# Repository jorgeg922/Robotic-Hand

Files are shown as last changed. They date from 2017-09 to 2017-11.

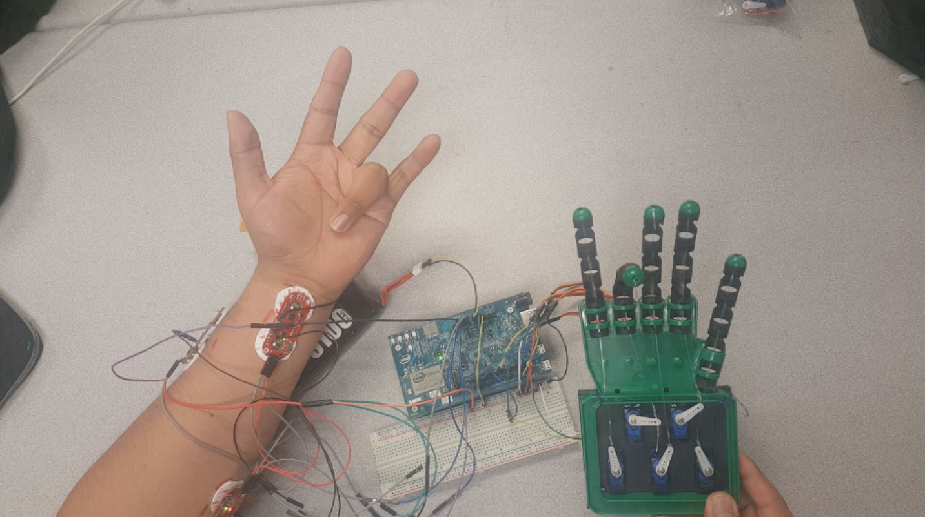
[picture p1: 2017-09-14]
Images/snip.PNG

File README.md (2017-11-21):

# Project Need-A-Hand
# RoboticHand

Team Members:
Espinoza, Jesus; Gonzales, Jorge; Guzman, Omar; Ladesma, MarcoAntonio

The purpose of this project was to develop a robotic hand that may be used to aid amputees regain full use of their hands.
This project, through the use multiple advanced sensors reads the eletrical differential potentials from an individual's arm muscles and
converts the signals to their equivalent PWM signal to move the fingers from the robotic hand.

Due to the complex nature of reading electrical signals from people's arms, this project includes a calibration procedure developed by the team mentioned above, which allows the user to more easily control the hand through his/her muscles. Furthermore, due to the different physical attributes of each individual the results may still vary as muscle location may differ per individual. However, in the documentation we have included a general diagram that may help you find the correct location of your muscles.

For set-up instructions and demonstration images/videos, please refer to the files included within this repository.

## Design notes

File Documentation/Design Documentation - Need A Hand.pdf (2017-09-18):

# Design Documentation

# Spring 2016

# Team 6: Need-A-Hand

## Group Members: MarcoAntonio Ledesma

## Jesus Espinoza

## Omar Guzman

## Jorge Gonzales

Table of Contents

## ABSTRACT

Need-A-Hand: Muscle Sensor Controlled Prosthetic Hand for those with Hand Disabilities

Need-A-Hand is a project to create a prosthetic hand that is controlled using muscle sensors in

the forearm. The purpose of this project is to build a prosthetic robotic hand to aid those

people who have a hand disability. The prosthetic hand will help those people regain some

hand ability to aid them in daily tasks like getting dressed, cooking a simple meal, grasping a

glass to drink water. In the end our goal is to make life easier to those with an unfortunate hand

disability.

If you look into hand anatomy, we can see that human fingers move with the muscles in the

palm and forearm. Instead of using those muscles in the forearm to move real fingers we will

use them to move our prosthetic hand fingers. This is where the basic functionality of our

prosthetic hand comes from. We will be using muscle sensors to read muscle activity in our

forearm. The muscle sensors read muscle contractions to get a signal. We then use those

signals to activate servos to individually move the fingers of the prosthetic hand.

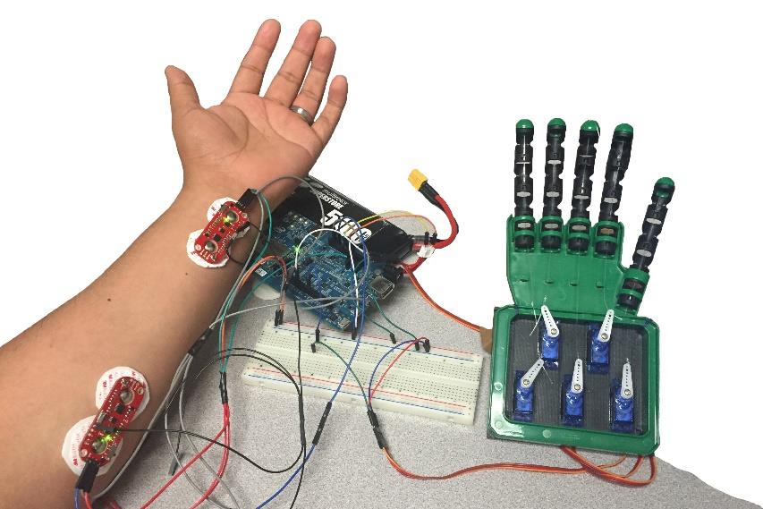
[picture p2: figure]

## Introduction

The motivation behind our project was that there are a lot of people with hand disabilities who

have lost their ability to complete daily tasks especially those of physical nature after having

one of their hands amputated such as war veterans or people suffering from malignant

diseases. Currently, the options on the market for people who have had one of their hands

amputated are to buy a plastic prosthetic hand or invest on a robotic prosthetic hand which can

cost up to $100,000 per unit.

However, these options are either insufficient to help an individual complete basic daily tasks or

too expensive for a common individual to afford. Therefore, with the inspiration to improve

people's lives, our project began as an idea to develop a robotic prosthetic hand that would

allow people to perform and complete necessary and essential tasks such as clothing

themselves more efficiently, driving, or even cooking by controlling each of the fingers in the

robotic hand. Our goal was to develop the robotic prosthetic hand that would result in an

inexpensive, but efficient product that would be easy for the person the use.

In understanding this project there were 3 major tasks to accomplish. First, we needed to figure

out how we would be reading the signals from the arm muscles that belonged to each

individual finger. Second, given the signal, we needed to find a way to interpret the signal and

pass it to our robotic hand for movement. Third, we needed to design our robotic hand in a way

that the fingers could move according to the data being received from the actual muscles

allowing the user to perform the desired task.

## Product Proposal both Fall and Spring Semesters

CPE 190: Project Proposal

Project Name: Need-A-Hand

Team 6 Members:

Espinoza, Jesus; Gonzales, Jorge; Guzman, Omar; Ladesma, MarcoAntonio

Purpose and Justification

The purpose of this project is to design and build a prosthetic robotic arm to aid those who

have lost part of their limbs in accidents or military combat. The prosthetic arm will help

improve the quality of life of those who have lost a hand by giving them the ability to once

again be able to perform basic daily tasks that may need the ability to use individual fingers in

order to accomplish them.

Statement of the Problem or Need

Many people have lost the ability to fully enjoy life due to the loss of an arm, either through

unfortunate life events or military combat. This has caused many people difficulties integrating

themselves into society because some of the simplest daily tasks such as changing clothes

required the use of both hands. This unfortunate disability has created a need for engineers to

develop replacement arms. The user will be able to control this robotic prosthetic arm through

the use of muscle sensors by reading the electrical signals outputted by the muscles that may

still remain in the arm. The robotic arm will simulate the functions of the original limb and will

allow its users to better perform their daily tasks by being able to move each finger individually

with the correct amount of force necessary to perform the task.

As of now, there are other robotic arms people have access to, but these arms are very costly

to the consumer and very few can afford them. However, with the introduction of development

microcontroller kits, people have access to the same technology many big firms do for a lot

cheaper. This project will allow more people to have access to a robotic arm that will improve

their quality of life by making use of devices that are available to the general public.

Project Deliverable and Beneficiaries

- Develop functionality code in C++ - includes code to pick up electrical readings from muscle sensors and map them to the servos.
- Create GUI for electrical signal readings in Java - includes code to read the electrical signals and outputs them to a graph in order to calibrate muscle sensors.
- Test prototype on selected subject – test the first prototype on a person who has full use of both arms.
- Second stage of the project will required a 3D printed hand to better fit the needs of the user.
- Test prototype on final subject – test final design on a person who has lost a partial arm (fall semester).
- At the end of the project, we hope to have a fully functioning prosthetic robotic arm. With the use of sensors, the user will be able to control the arm and will be able to perform simple tasks such as cracking an egg open with both arms.

Knowledge Areas Needed for Project

- Software engineering
- Hardware design
- Circuit Analysis

Time Factors

We would like to start with the research of this project as soon as possible. Documentation of

the hardware as well as the software design will need to implemented as soon as possible in

order to complete the project. The end of the semester is coming near and we would like to

have a completed budget in the following week.

Project Assumptions and Constraints

Assumptions:

- The prosthetic arm will be able to be tested on a person with both arms
- All members are able to learn the required material in the allotted time
- All hardware will be available for purchase
Constraints:
- The prototype must be completed before the end of the Spring 2016 semester

Project Risks

- There is a risk that the hardware may not be available for purchase or that the project may need more skills in the field of mechanical engineering

## WBS and Schedule including milestones

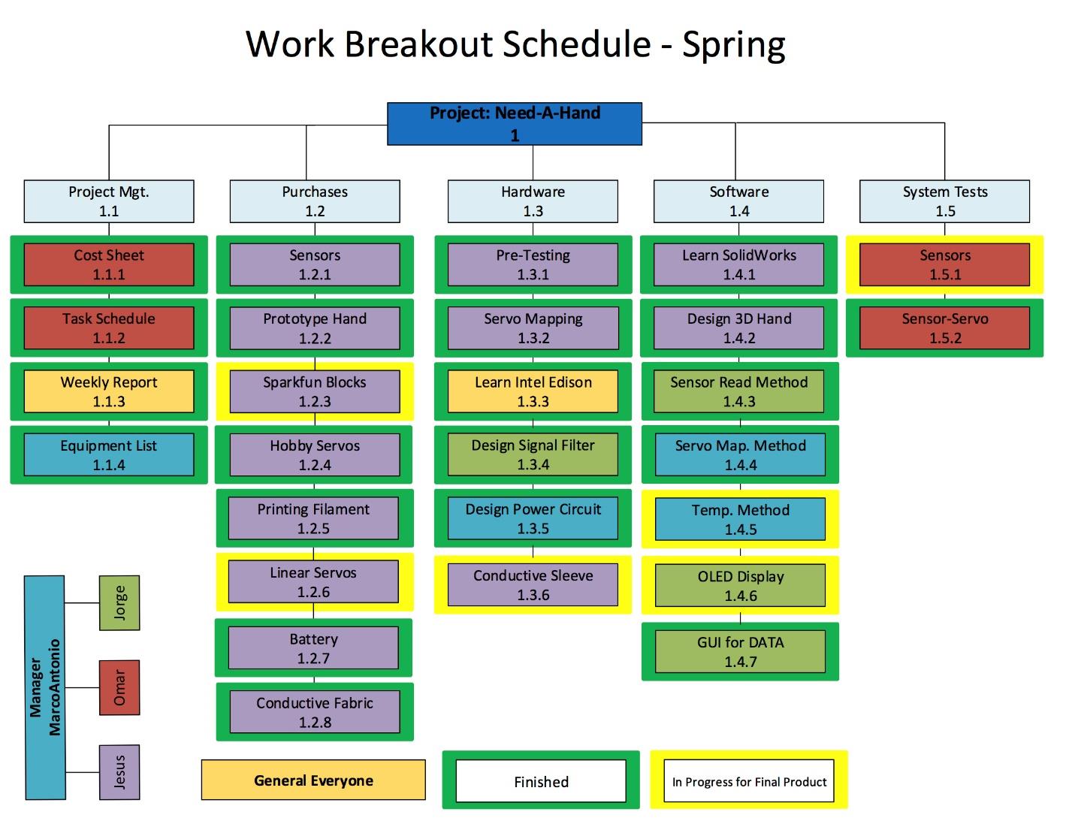
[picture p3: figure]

Above we have our WBS for the spring. It is color coded to highlight which team member is

assigned which task. It also highlights which tasks have been finished and which ones are in

progress or to be implemented in the final product design.

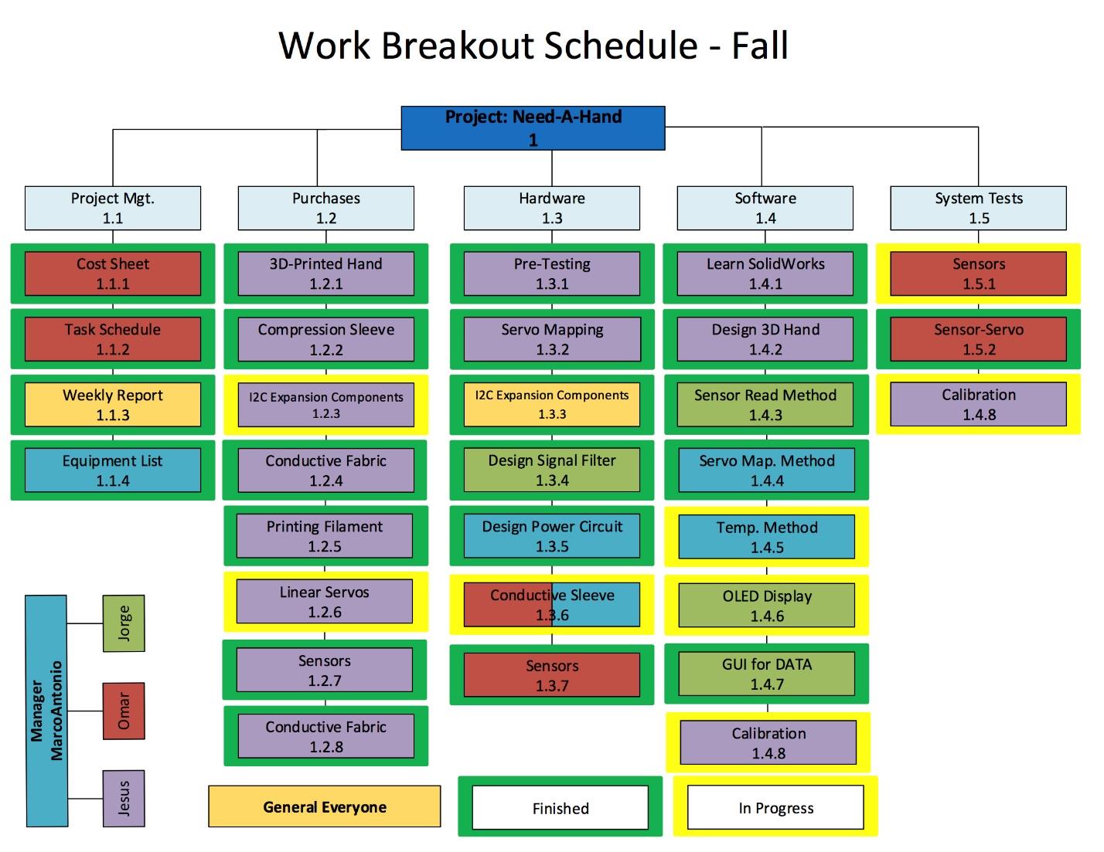
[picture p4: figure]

Above we have our WBS for the fall semester. Again just like before it is color coded to

highlight which team member is assigned which task. It also highlights which tasks have been

finished and which ones are in progress. As you can see it includes many components of the

previous first phase design as we are still using some of the components and continue

optimizing those parts.

ID | Task Name
1 | 1 Need‐A‐Hand
2 | 1.1 Project Mgt.
3 | 1.1.1 Cost Excel Sheet
4 | 1.1.2 Tasks Schedule
5 | 1.1.3 Weekly Progress Report
6 | 1.1.4 Equipment List
7 | 1.2 Purchases
8 | 1.2.1 Muscle Sensor
9 | 1.2.2 Prototype Hand
10 | 1.2.3 Sparkfun Blocks
11 | 1.2.4 Hobby Servos
12 | 1.2.5 3D Printing Filament
13 | 1.2.6 Linear Servos
14 | 1.2.7 Battery
15 | 1.3 Hardware
16 | 1.3.1 Pre‐Test Muscle Sensor
17 | 1.3.2 Map Servo with Muscle Sensor Readings
18 | 1.3.3 Learn Intel Edison Hardware
19 | 1.3.4 Design Signal Filter for Muscle Sensor Reading
20 | 1.3.5 Design Power Circuit
21 | 1.4 Software
22 | 1.4.1 Learn SolidWorks
12 | 17 | 22 | 27 | 3 | 8 | 13 | 18 | 23 | 28 | 2 | 7 | 12 | 17 | 22 | 27 | 2 | 7 | 12 | 17 | 22 | 27
016 | March 2016 | April 2016 | May 2016

Task
Split
Milestone
Summary
Project Summary
Inactive Task
Inactive Milestone

Inactive Summary
Manual Task
Duration-only
Manual Summary Rollup
Manual Summary
Start-only
Finish-only

External Tasks
External Milestone
Deadline
Progress
Manual Progress

Project: Project1
Date: Tue 3/15/16

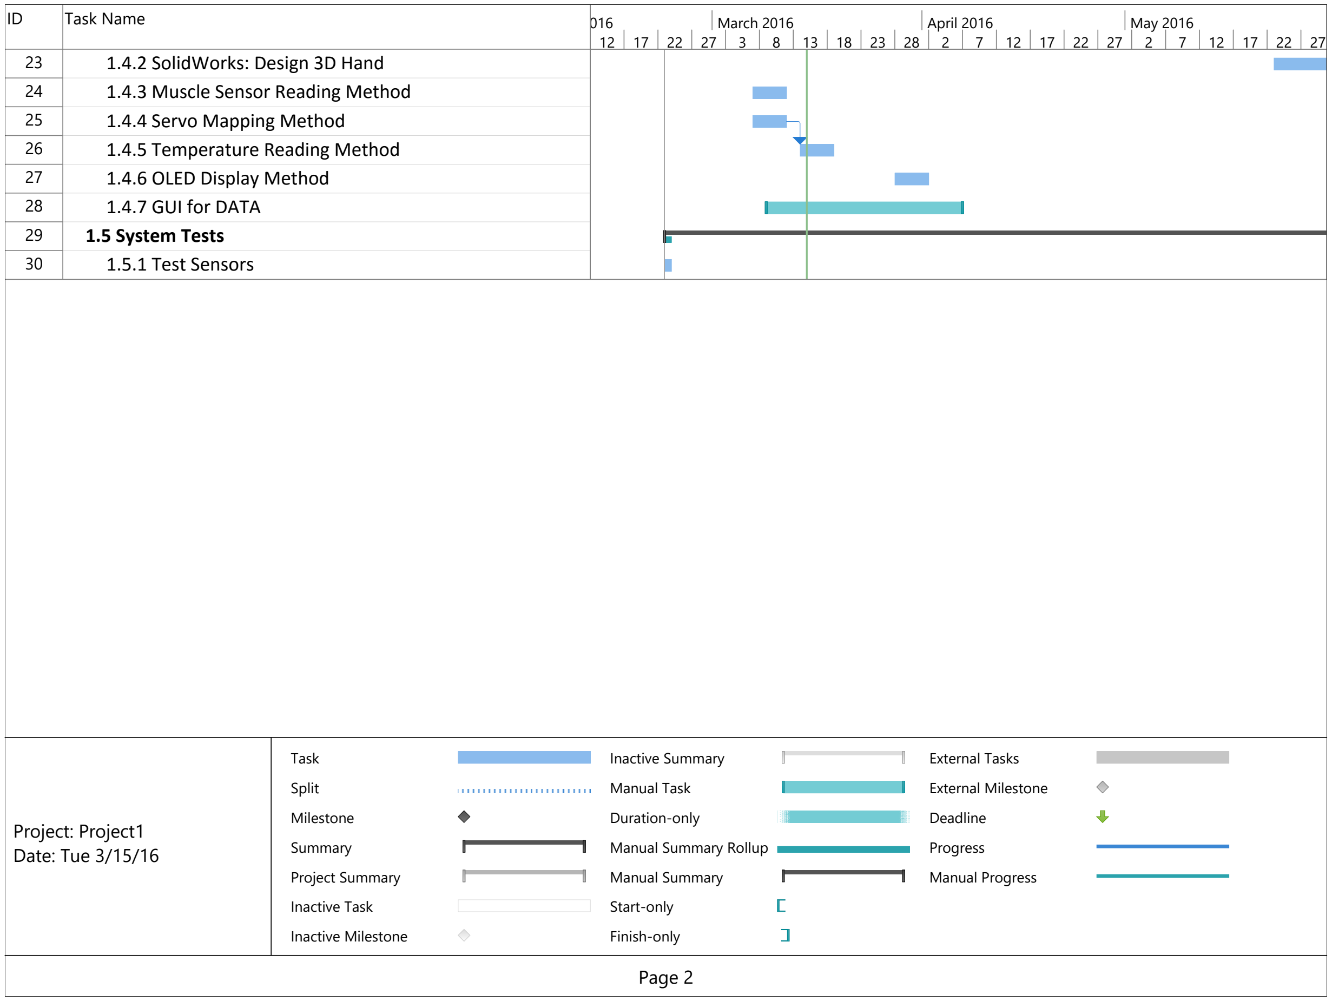
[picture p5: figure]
Task Name; 1.4.2 SolidWorks: Design 3D Hand; 1.4.3 Muscle Sensor Reading Method; 1.4.4 Servo Mapping Method; 1.4.5 Temperature Reading Method; 1.4.6 OLED Display Method; 1.4.7 GUI for DATA; 1.5 System Tests; 1.5.1 Test Sensors; March 2016; April 2016; May 2016; Task; Split; Milestone; Summary; Project Summary; Inactive Task; Inactive Milestone; Inactive Summary; Manual Task; Duration-only; Manual Summary Rollup; Manual Summary; Start-only; Finish-only; External Tasks; External Milestone; Deadline; Progress; Manual Progress; Project: Project1 Date: Tue 3/15/16

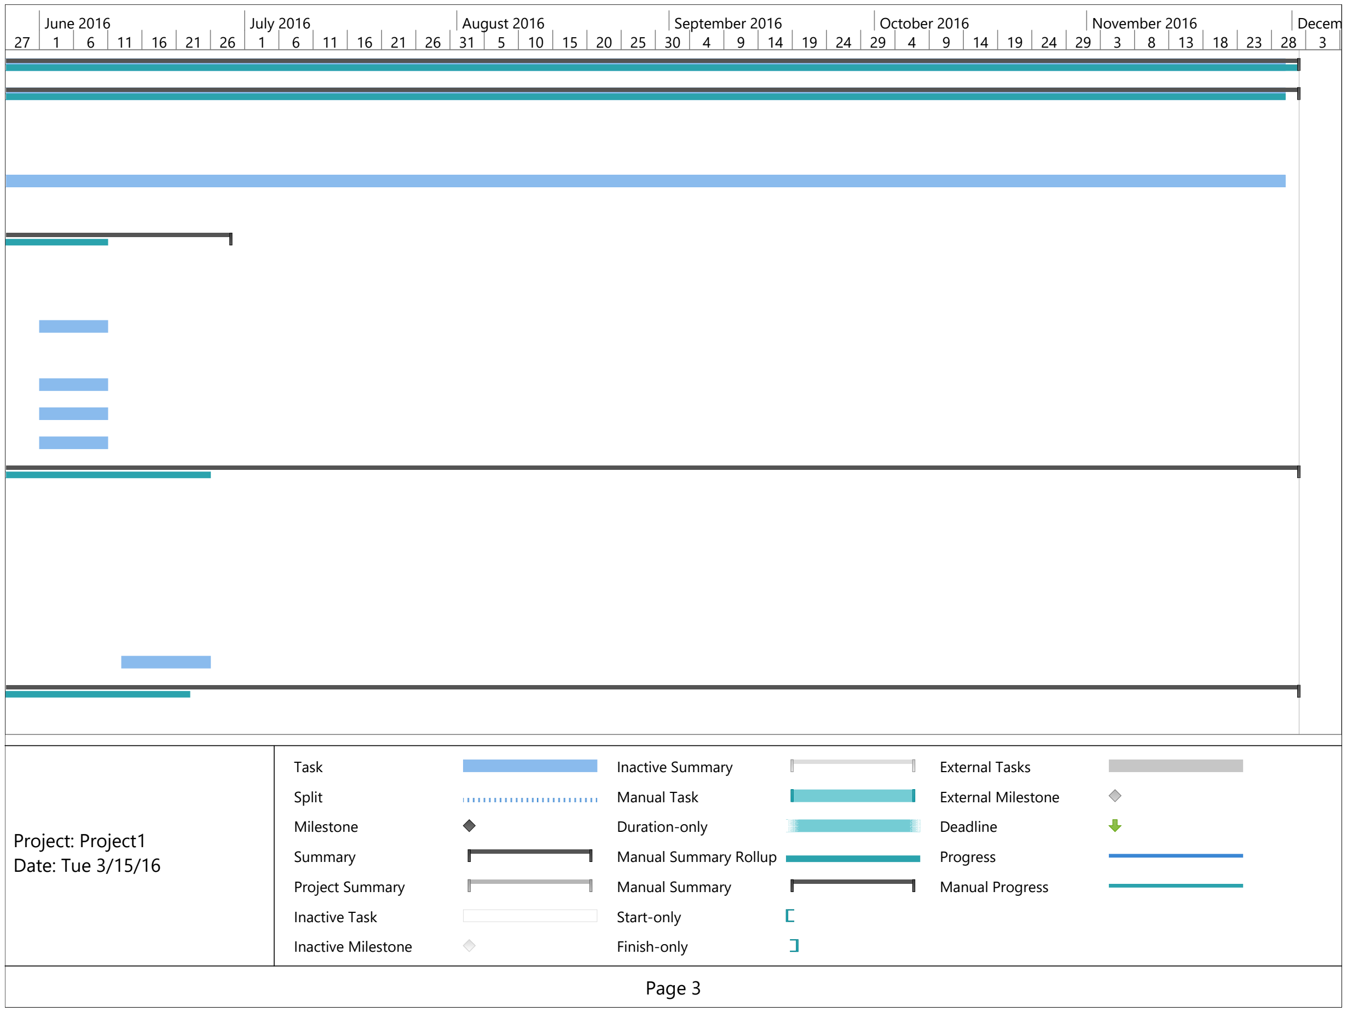
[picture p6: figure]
June 2016; July 2016; August 2016; September 2016; October 2016; November 2016; Decem; Task; Split; Milestone; Summary; Project Summary; Inactive Task; Inactive Milestone; Inactive Summary; Manual Task; Duration-only; Manual Summary Rollup; Manual Summary; Start-only; Finish-only; External Tasks; External Milestone; Deadline; Progress; Manual Progress; Project: Project1 Date: Tue 3/15/16

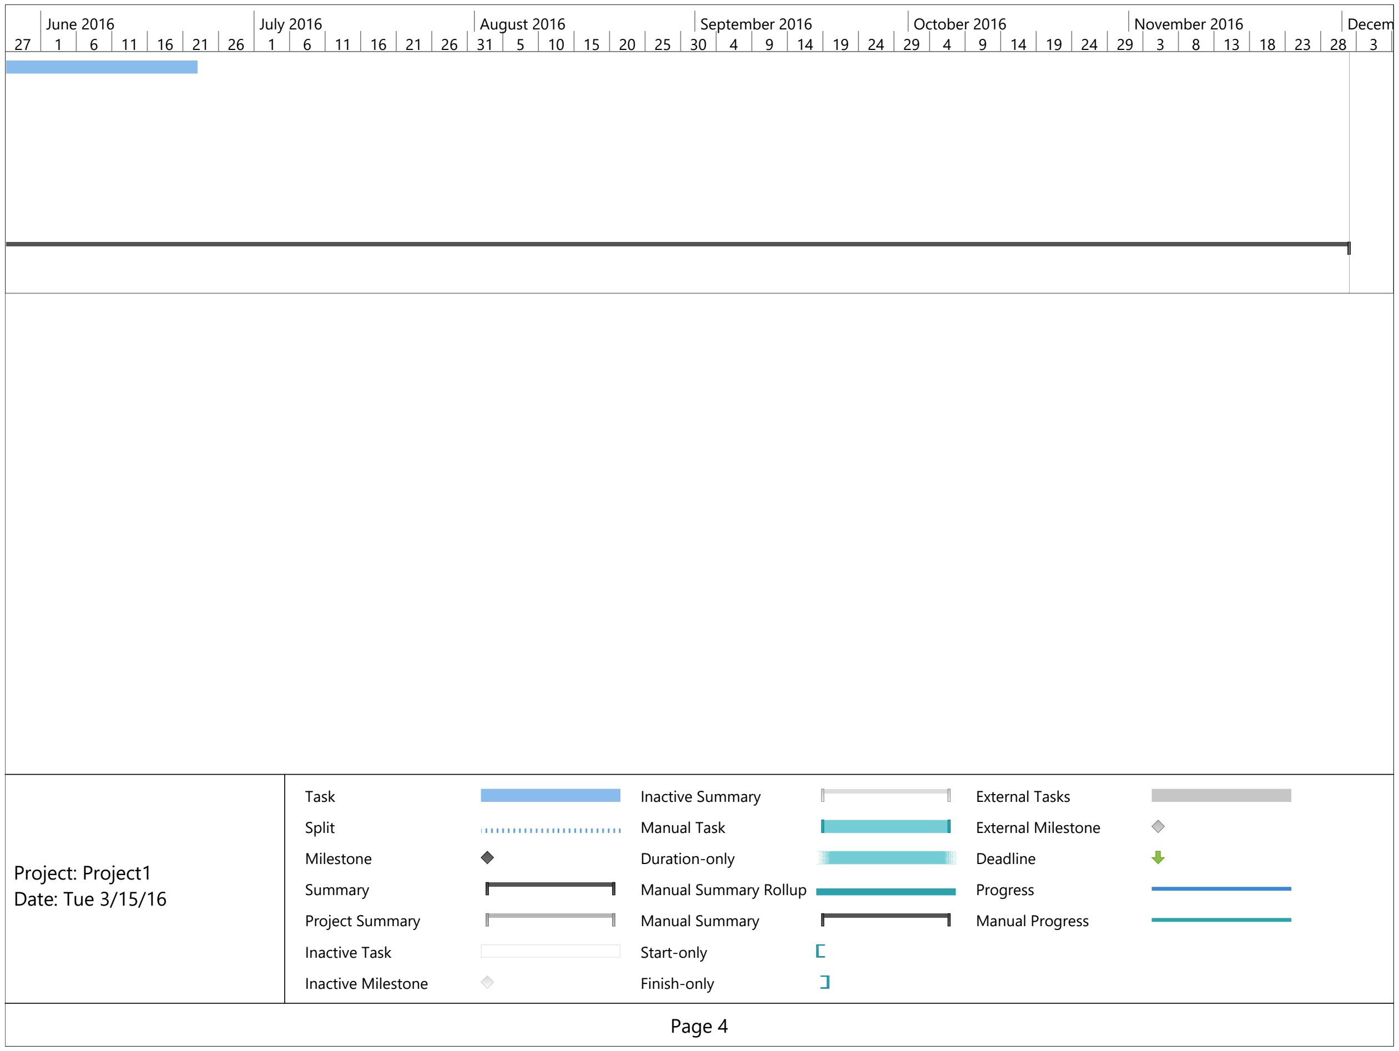
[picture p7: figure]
June 2016; July 2016; August 2016; September 2016; October 2016; November 2016; Decem; Task; Split; Milestone; Summary; Project Summary; Inactive Task; Inactive Milestone; Inactive Summary; Manual Task; Duration-only; Manual Summary Rollup; Manual Summary; Start-only; Finish-only; External Tasks; External Milestone; Deadline; Progress; Manual Progress; Project: Project1 Date: Tue 3/15/16

## Funding Proposals

The goal of our project is to engineer an affordable prosthetic hand to aid those for

hand disabilities. For the reason of making it affordable this project should be affordable for

ourselves as well. We are funding the project ourselves not only to emphasize the affordability

but also to have full ownership of any biomedical engineering advances we may succeed in.

Below is the total cost of the project broken down by components.

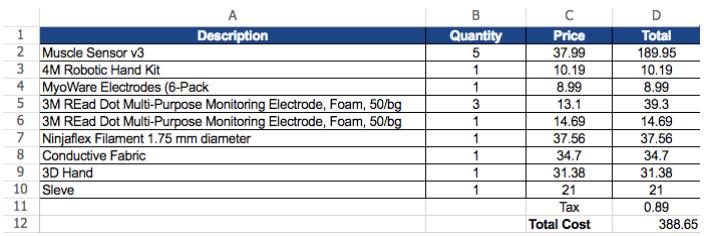
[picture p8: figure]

We have yet to purchase our linear servos and I2C components. We estimate that will bring

our cost up to about $600. Even then that cost between 4 people is only $150 each. Which is

affordable for a yearlong project. This is why we decided to fund the project ourselves. In the

end we also get full ownership so that is good.

## Team Member Tasks

Once we determined the work breakdown schedule, we needed to make each member of the

group responsible for certain tasks. We split the tasks amongst ourselves by assigning a

responsible person as well as a back-up person to a task. The "back-up" was set up in case

something happened to the person responsible for the task in order to avoid delays in the

development of the project.

We broke down the tasks in the following way:

Task | Assigned to | Backup
Cost Sheet | Omar | Jesus
Keeping track of the cost of every component being purchased for the development of the project. Also, keeping track of how much each member owes
Weekly Report | MarcoAntonio | N/A
Updating the weekly report with the team minutes from each week's minutes. Also, responsible for submitting the report after each member has updated the report with their respective task progress.
Equipment List | MarcoAntonio | Jesus
Responsible for tracking the amount of parts being purchased for the project. Also, responsible for keeping track of the equipment being used and for putting in a purchase request if we run of out parts such as gel pads and/or wires
Purchases of components | Jesus | MarcoAntonio
Responsible for the purchase of the components necessary to complete the project after request has been agreed upon by the member of the group. Also, responsible for updating the cost sheet after each purchase
Learning Intel Edison tools | General Team | N/A
Each member of the team is responsible for learning the appropriate tools within Intel Edison for the purposes of this project. This includes, but is not limited to learning the IDE by Eclipse which is used to compile our C++ based code.
Design Signal Filter | Jorge | Jesus

Responsible for the development of a system to filter the signals being read by the muscle sensors whether by using additional hardware or developing some code

Design Power Circuit | MarcoAntonio | Omar
Responsible for the design and implementation of the power circuit
Conductive Sleeve | Jesus | MarcoAntonio
Responsible for the design and implementation of the conductive sleeve to better pick up the electric signals from the muscles
Learn SolidWorks | Jesus | General Team
Responsible for learning SolidWorks which will be used to design the custom 3D hand for the fall semester
Design 3D Hand | Jesus | MarcoAntonio
Responsible for the design of the 3D hand to be used on the amputee. This 3D hand is supposed to fit in a real human being.
Method to read sensor signals | Jorge | Jesus
Develop C++ code to read the signals from the MyoWare muscle sensors and pass them to the Intel Edison
Method to map the servos | MarcoAntonio | Jesus
Develop C++ code to convert the stored data from the muscle sensors into a signal that can be mapped using the servos attached to the robotic hand in order to produce movement
Temperature Method | MarcoAntonio | Jorge
Develop C++ code to be able to read the surrounding temperature and report it back to the user
OLED Display | Jorge | Omar
Responsible for the implementation of the OLED display to report the surrounding temperature
Graphic User Interface | Jorge | Jesus
Responsible for the graphic user interface which will plot each signal being read from the muscle sensors
Sensor Testing | Omar | MarcoAntonio
Responsible for the testing and debugging of the sensors and any other hardware/software that may be showing errors
Sensor-Servo communications | Omar | Jorge
Responsible for the communications between the sensors and servos. This includes, but is not limited to wiring and circuit analysis

## User Manual

The artificial robotic hand uses 5 muscle sensors (Figure 1.1) to obtain an analog signal from the

muscle contractions. Which are the filtered and translated to servo positions which controls

each finger.

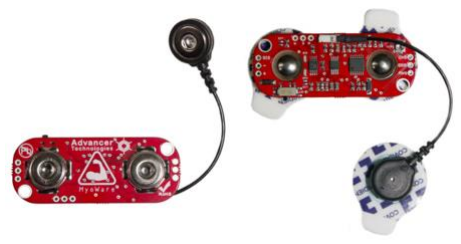
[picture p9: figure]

Figure 1.1 (http://www.advancertechnologies.com/p/myoware.html)

Muscle Position and Sensor Placing

The five sensors will be placed around the forearm and a common ground on the elbow. Please

see the muscle sensor placement (Figure 1.2) to find the best muscle position to obtain a clean

signal.

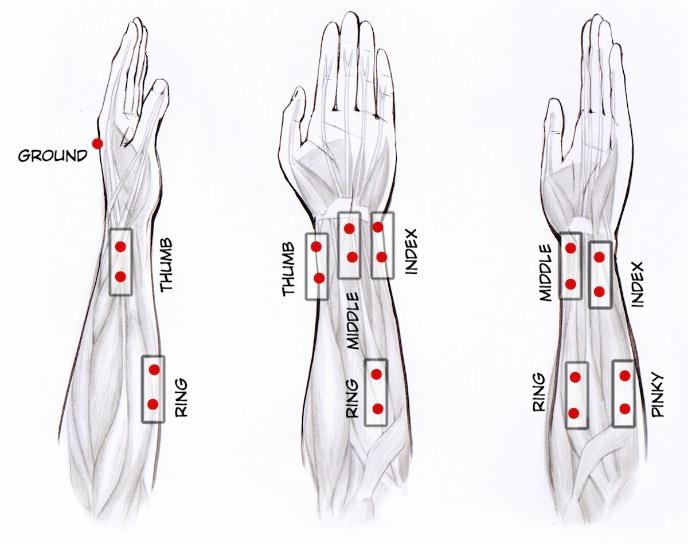
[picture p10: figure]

Figure 1.2 (https://backyardbrains.com/experiments/robothand)

The sensors will require two electrode pads each and an electrode pad for the common ground.

Before placing each sensor on the forearm, make sure to clean your skin with rubbing alcohol,

or conductive gel to obtain better readings.

Each sensor is labeled as P, R, M, I, and T (Pinky, Ring, Middle, Index, and Thumb) place each

sensor according to the position from Figure 1.2. Place the common ground electrode near a

bone, we strongly suggest using the elbow since there are not many muscles around the elbow.

Each sensor will have four wires connected, Signal, Power, Ground, and Reference electrode.

Make the following connections to each sensor.

Muscle Sensor | Intel Edison pin
+ | 5V
- GND
Sig | A0-A4
R (Reference Electrode | N/A

The reference electrode will connect each sensor to each other using the 1:4 female connector

cable. The pinky sensor will be closed to the elbow, use this sensor to obtain the reference

electrode from the elbow. Then connect the 1:4 female connector cable from the “R” pin on

the sensor to the “R” pin on the other four muscle sensors.

Connect the battery to Intel Edison, you should see the sensors LED’s light up. The Servos

should start moving now.

Muscle Sensor Calibration

If the servos are not moving full range and/or not responding to the muscle sensors. You will

need to start the calibration process by pressing the calibration button. Once the calibration

process starts, you will need to do two actions to calibrate the sensors for each finger

individually.

1. To define the baseline, relax your muscle for 10 seconds.
2. To define the Max value, you will need to pulse the muscle by contracting the muscle

and relaxing multiply times for 10 seconds.

3. Repeat these steps for each sensor.

Once the calibration process is finished, the servos should be responding. If they are not, you

can attempt to calibrate again.

## Design Documentation (Spring & Fall)

The purpose of this design is to aid people without a hand, whether they lost their hand

in combat, birth defects, or an unfortunate tragedy. Our design will use the Intel Edison to take

analog signals generated from muscle contraction and translate/convert the signals to hand

movement that will be used to control a 3D printed artificial hand. The user will mount all the

sensors and the Edison module on their forearm.

In the spring semester we were able to design and built a prototype design to prove the

idea and logic behind our design. Currently we have four sensors reading muscle contraction

signals, the logic for five sensors is implemented and tested but due to a hardware limitation on

the Intel Edison Arduino board, which is only capable of driving four PWM signals at a time. This

will be addressed in the fall semester.

During the spring semester we came across a couple of obstacles that we successfully

overcame. Our first obstacle was finding a power supply to drive five servos. Since the servos

can draw up to 2A each, we are using a Li-Po battery that is able to continuously output 150A

which is more than enough. This gave us the idea to use a smaller battery for the final design,

since the Edison module is low power the battery will last longer. We can design an algorithm

that will help decide to turn off the power being applied to the servos in order to save battery.

Another challenge that we overcame was getting the muscle sensor signals. Since the muscle

sensors contract the signal varies between 1 – 2 Volts. The signals were originally mapped to

the servos without being modified. What we decided to do, was design the calibration

algorithm to calibrate the sensors, essentially what it does is find the baseline and max value for the sensors. Then we take around 1 hundred samples and find the average to rule out the

outliers.

For the Fall semester we plan to migrate our design to the Intel Edison breakout board,

which will allow us to condense our design into a smaller form factor that will be mounted on

the forearm of the user. We also intend to implement an I2C OLED display to provide the user

visual feedback from calibration process and/or battery voltage.

## Software Block Diagram & Documentation

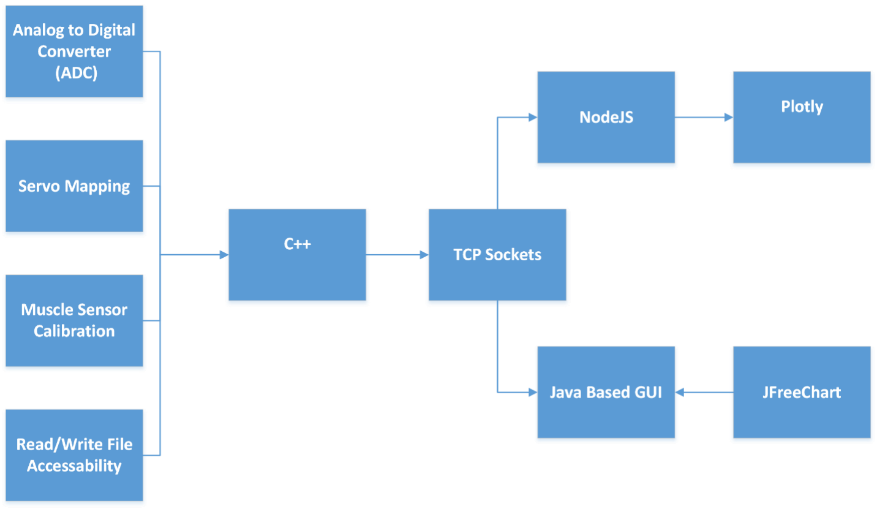
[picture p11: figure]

The software designed in our project is based on C++ and NodeJS, both which are

simultaneously running on the Intel Edison Development Platform. The Intel Edison board is

running an embedded version of Linux based on the Yocto Project which has Wi-Fi capabilities.

The C++ contains the following logic.

- Read analog signals and converting to digital.
- Mapping the sensor readings to an angle to be written to the servo
- Client TCP socket
- Muscle sensor calibration logic
- I/O Interfacing and Initialization
- Read and Write to file where calibration values are stored.

The NodeJS contains the following logic.
- Server TCP socket
- Plotly API to send data to Graph

The Java based GUI contains the following logic.
- Server TCP socket
- JFreeChart to graph data

## Hardware Block Diagram & Documentation

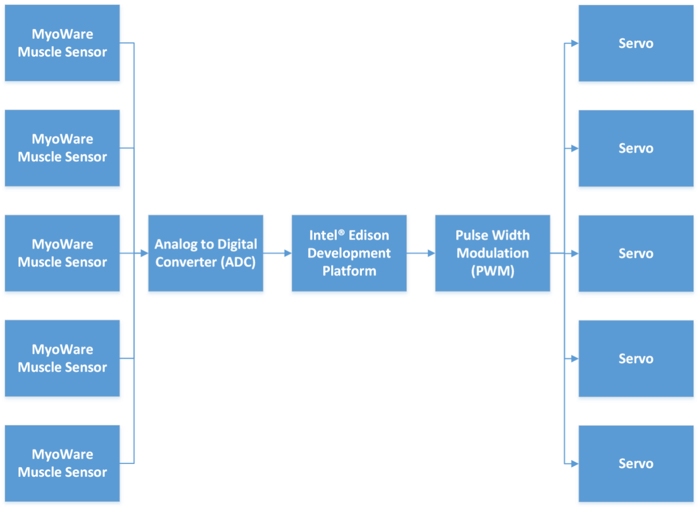
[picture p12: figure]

The Intel Edison Development platform was our best option for our project for various reasons.

The fast prototyping can then be easily transferred into a smaller board to design wearable

technology. In this case, the Edison module will be mounted onto the design that will be on the

users forearm along with all the sensors. The muscle sensor reads EMG signals that can be read

with an ADC chip.

The current Arduino Expansion board has an analog to digital (ADC) chip which allows us to

sample a analog signal, a pulse width modulation driver which allows us to send a pulse signal to the Servos. A Bluetooth and Wi-Fi module are built in to the module that allows us to

connect to a network to send data to the GUI or Plotly to graph the muscle sensor readings.

The Intel Edison module will allow us to transfer our current project and enhance the hardware

by using external PWM and I2C chips to expand the capabilities but at the same time

condencing our project to allow the comfort of being on the forearm of a person.

## Software

In order to develop the software necessary to operate the robotic prosthetic hand, we decided

to write the code in C++ language using the Eclipse IDE.

The following are some excerpts of the code we wrote in order for the hand to operate.

int mmap(int, int, int, int, int);

void my_socket(int, int, int, int, int);

void readCalibration();

void Calibration();

In the portion of the code shown above, we simply declared the mmap function used to map

the signals to the servos. We declared the socket as well as the calibration methods that we will

be demonstrating later in this report.

int s0 = socket(AF_INET, SOCK_STREAM, 0);

char const *peerHost = "127.0.0.1";

short peerPort = 8589;

struct sockaddr_in peeraddr;

In this portion of the code we defined the socket and assigned the IP address the socket will be

communicating with. We also assigned the port number.

upm::ES08A *servo0 = new upm::ES08A(3);

upm::ES08A *servo1 = new upm::ES08A(5);

upm::ES08A *servo2 = new upm::ES08A(6);

upm::ES08A *servo3 = new upm::ES08A(9);

servo0->setAngle (180);

servo1->setAngle (180);

servo2->setAngle (180);

servo3->setAngle (180);

Next, we set up the pins from which the servos would be acquiring the signal first acquired

from the muscle sensors to produce movement in the fingers. We also set the servos to an

initial angle of 180 degrees that signified the hand was relaxed and fingers spread out.

int count = 0;

int samples = 30;

for (;;) {

usleep(3000);

pinky_val += a0->read();

index_val += a3->read();

my_socket(pinky_val,ring_val,middle_val,index_val,0);

if(count == samples){

pinky_val = (((pinky_val+5)/10) * 10)/samples;

…

In the above code, we set up some parameters before the signal was passed on to the servo to

be mapped. We decided to take 30 data samples. After these samples were taken and added

together, the number was rounded to its closes multiple of 10 and the average was taken. This

allowed us to reduce the shaking of the hand and resulted in smoother and more accurate

movement.

if((pinky_low) < pinky_val && pinky_val < (pinky_high + 1)){

pinky_servo = mmap(pinky_val, pinky_low, pinky_high, 180, 0);

servo0->setAngle (pinky_servo);

}

After the calculations previously mentioned were done, we compared our new value to the

high and low threshold and if it was in between these values, it was then passed unto the servo

to rotate to certain degree in order to move the robotic fingers.

void readCalibration(){

ifstream file("/home/root/calibration.txt");

if(file.is_open()){

for(int i = 0; i < 10; i++){

file >> cali_val[i];

}

}

file.close();

}

In the above method, we set up the way in which we would read the high and low threshold

values stored in a text file.

void Calibration(){

int tmparray[10] = {0,0,0,0,0,0,0,0,0,0};

int count;

int tmpvar = 0;

int samples = 1500;

printf("Order of calibration: Pinky, Ring, Middle, Index, Thumb\n");

printf("Calibrate each finger twice: Baseline, then Max\n");

printf("Calibration process will start in 3 seconds\n");

printf("\n");

sleep(3);

printf("Calibrating Baseline for Pinky\n");

for(count = 0; count < samples; count++){

tmpvar += a0->read();

usleep(5000);

}

tmparray[0] = tmpvar/samples;

tmpvar = 0;

printf("Calibrating Max for Pinky\n");

for(count = 0; count < samples; count++){

tmpvar += a0->read();

usleep(5000);

}

ofstream file("/home/root/calibration.txt");

if(file.is_open()){

for(int i = 0; i < 10; i++){

file << tmparray[i];

file << " ";

}

}

file.close();

printf("Calibration Finished...\n");

}

void my_socket(int sval1, int sval2, int sval3, int sval4, int sval5){

const void *data;

std::string sensor1 = SSTR( sval1 );

std::string sensor5 = SSTR( sval5 );

std::string my_string = sensor1 + "," + sensor2 + "," + sensor3 + "," + sensor4 + "," + sensor5;

data = my_string.c_str();

write(s0, data, 20);

}

In the Calibration method, which is one of the most important parts of this code, we acquire

the values for the high and low threshold for each individual finger. The above code only shows

the code for one finger as we found it redundant to post the code for each individual finger

since the code is the same. Nevertheless, we acquired the threshold values by reading 1500

samples and averaging them out. For the low threshold value we maintained our hand relaxed,

and for the high threshold value, we contracted our finger fully several times until the

calibration process was completed.

## Hardware

MyoWare Muscle Sensors

The Myoware muscle sensor measures muscle activation via electric potential, referred to as

electromyography (EMG). This muscle sensor is place around our forearm to read finger muscle

activity in our arm due to finger movements.

http://www.mayoclinic.org/tests-procedures/electroconvulsive-therapy/basics/definition/prc-

20014183

Hobby Servos

For the prototype, we used hobby servos which are mapped using PWM ports from the Intel

Edison platform. These servos are great for prototype purposes. Each servo has a 0 to 180

degree rotation movement. We tied fishing line to each of the servos and to each of the fingers

to implement the movement of each of the fingers.

Intel Edison

The Intel Edison is an open source development environment that supports many different

programming languages such as C, C++, Java, Python, and Arduino Sketches just to name a few.

It also comes with integrated Wi-Fi capabilities that makes it very convenient for uploading

source quickly.

Testing Hand

The Robotic hand from KindzLabs makes a great prototyping hand for our project. This hand

comes as a kit that includes the hand, string, and five rubber fingers. We tied fishing line to

each of the fingers, which are also tied to the servos.

3D Printed Hand

For our final product we will be using a 3D printed hand. This hand has a more human based

design compared to the testing hand. Each of the fingers has 3 joints that uses flexible material

called NinjaFlex. This file was found online from enablingthefuture.org and then printed at a 3D

printing shop. The joints were then printed using own our equipment.

## Software Testing Plan

As we progressed through our project there were many stops we had make in order to

test the multiple software components within our project. Among the components that we

tested were the code used to for main functionality of the robotic hand, the Java based code to

graph the data from the sensors that will serve as our main graphic user interface next

semester, and the code used to get the data graphed using Plotly - a web based graphing

interface.

First, as we wrote the code that would be uploaded to Intel Edison, we encountered many

difficulties, some of which included misconnections of the sockets, corruption of the eclipse IDE

(caused by the download of a set of libraries that were not meant to be used), and lag caused

by all the functionalities we had included within the code. Therefore, we had to test each of this

components until they worked properly.

Also, when coding our graphic user interface in Java, we encountered some additional

difficulties. Instead of running indefinitely or until stopped by the user, the sockets ran only

once before terminating the process despite being in a forever for-loop. This meant that if Intel

Edison stopped sending data at any one point, the Java based GUI would stop working

completely and would ignore any further data received. We had to test and debug this piece of

code and although somewhat successful, we decided to leave this portion of our project for the

following semester as we plan to incorporate some additional functionalities to our GUI.

Lastly, we wrote a code to use a web-based graphing interface, called "Plotly". With this

interface, we were able to graph every signal coming from the sensors. However, these was

also encountered with some difficulties. Our initial attempts at graphing our data in Plotly were somewhat successful because the time series graph was latency. We figure out it was because

too many resources were being use in the Intel Edison, so we have to figure out a way to

decrease this, and decided to not use the graphing interface at the same time as the arm and

only a method to calibrate the prosthetic hand. On the good side, however, our testing of Plotly

allowed to easily plot all 4 signals from the muscles sensors and helped us gain a better

understanding of the threshold values from the muscle sensors. In the future, our approach to

testing our software will be to program blocks of code and start testing them before moving on

another block hopefully reducing the amount of errors we will get.

## Hardware Testing Plan

1. Test each Myoware sensor to make sure we can get adequate muscle readings from

them. Test that the electrodes can stick well and get good readings. Test for faulty

sensors.

2. Test Intel Edison. Make sure the wireless communication is working properly. Test that

each port necessary is working properly.

3. Test Hobby Servos. Run test on hobby servos to make sure they are fully functional.

Test for delay and smooth movement of the servos. No faulty Servos. Test to make sure

some don’t get too hot. They might be faulty.

4. Test battery. Test to see if battery can power the Intel Edison and the 5 servos

simultaneously.

5. Test Oscilloscope. In our case we used our Analog Discovery Kit to use the oscilloscope

tool. Make sure the scope is working and we know how to operate it.

6. Once we have done all components testing. Now integrate parts together and test to

make 1 finger operate properly. Map sensor to servo and servo to robot finger to get

proper movement.

7. Test to get multiple fingers operating at the same time. (There will be interference

between the fingers.).

8. Test 3D-Printed Hand for functionality and durability. Test that all finger parts fit

together and joints fit properly giving the hand good movement.

9. Test the conductive material. Test the conductive material to make sure it conducts

efficiently enough. Make simple led circuit using conductive material to turn led on.

10. Integrate conductive material into sleeve design and test for one muscle sensor working

properly with the sleeve.

11. Once you have one muscle sensor working with the sleeve integrate the rest of the

sensors and test the functionality.

## Integration Plan

1. The first step in our integration plans is to make sure all the hardware and software

components are functioning properly individually.

2. The second step is to set up our project to get one functional finger working. We will

use one Myoware muscle sensor set to our forearm. We need to wire that sensor to the

Edison platform board so get power for the sensor and from there map the sensor

reading to a servo. The Analog signal is converted to a digital signal that the servo can

read. The servo then gets activated and is routed to a finger on the testing hand to

simulate movement.

3. Once we have one functional finger we will integrate more fingers adding 1 more at a

time. For this first phase our current Edison platform only has 4 PWM ports so we will

only use 4 fingers for the first phase. The integration of multiple fingers causes

interference between the fingers. This is where calibration software is integrated to get

more clear readings from each finger.

4. We will also integrate the GUI at this point to help us see all finger signals. This helps us

see how finger signals interfere with each other. We then adjust sensor placement and

sensor ranges to reduce the interference.

5. At this point phase 1 will be finished and we will move on to working on the final

prototype. This includes the 3D printed hand design, smaller Edison expansion board,

and a conductive sleeve.

6. The 3D hand is used in our final product to give the prosthetic hand some actual

functionality. The 3D hand will look nicer and actually be able to pick objects up.

7. The smaller expansion board will be integrated to make our design smaller. We need a

small compact wearable technology. Our current testing board only has 4 PWN ports

and is too robust to be worn comfortably. Smaller expansion components will be very

useful to integrate in our final design.

8. The conductive sleeve will be integrated for two purposes. The first reason is to

function as reusable electrodes for the muscle sensors. Having to stick electrodes to

your arm after every use is really inefficient. The conductive sleeve will replace the

electrodes make the sleeve easy to put on and take off. The sleeve will also help clean

up the final build of the prosthetic hand design. It will help hide all the wires.

9. Last we will integrate a better bracket for the 3D printed hand and the servos to be

mounted on. The bracket will be 3D printed to hold the servos in the best convenient

way.

## Accomplishments

Without doubt this semester was full of challenges but it was also full of accomplishments. At

the beginning of the semester we had a vision of how our project would look like and how it

would operate but we had little idea on how this would have to be done. To make the whole

project more manageable and approachable, we learned about Work Breakdown Schedules

(WBS) and Scheduling. These both concepts helped the team divide the workload and

assignments for better progress of the project. Having weekly reports also contributed to the

success of this project. These weekly reports assisted the team with the appropriate updates of

each of the tasks that were accomplished for a given week. Following these guidelines made

the process through this project much easier.

In terms of the project itself, the team made many accomplishments throughout the semester

which concluded with the first prototype of our design. At the beginning of the project, all of us

had minimum knowledge on muscle sensors, Electromyography (EMG), prosthetic hands, and

muscle placement. We all started doing our research on all of these concepts and starting

figuring things out. Our first accomplishment was selecting the appropriate muscle sensors that

would serve our needs. We came across the MyoWare Muscle sensor and decided to go with

this sensor because it small, convenient, and reliable. Once we had the MyoWare in our hands,

we tested it and became familiar with its functionalities. We have also accomplished getting

familiar with the Intel Edison Platform. We acquired knowledge on all the different

functionalities that the Intel Edison can provide. Using its Wi-Fi functionality, we are able to

code the board wirelessly which was very helpful for testing purposes. Our major

accomplishment this semester was being able to properly read four out of the five finger muscle signals and mapped them to its respective servos. For next semester we plan on

resolving all the issues that we faced this semester. First of all, we will be solving the

interference between the index and the middle finger. Secondly, we will be building a

compression sleeve in which we will be placing the muscle sensors. Lastly, we will also be

switching our prototype robotic hand for a 3D printed hand.

## Summary

Our goal is to design and build a robotic hand that will aid those who have lost a hand in an

accident. This robotic hand will be capable of picking up small objects and perform simple daily

tasks such as holding a ball. In this first semester of senior design class, we have completed all

the tasks that were set at the beginning of the semester. Our team was able to successfully

design and build a robotic hand prototype that successfully reads muscle signals from the

forearm. The team began this project with minimum knowledge about muscle sensors and EMG

signals but we obtained the necessary knowledge through research. Moreover, our current

prototype can successfully map four out of the five fingers from the muscle sensors to the

servos. For better results, we have also created an algorithm which calibrates the muscle

signals taken from the forearm. The current prototype also displays each of the muscle signals

on Plotly, which is an online charting service. Some of the major problems we faced was the

interference between the middle and the index finger and finger contraction problems. To

further explain, when a finger is flexed the signal spikes up but when it is left contracted the

signal gets weaker. Our plans for next semester consist of solving the interference issue and

finger contraction issues, build a compressive sleeve that will replace the use of electrodes, and

switch from a prototype hand to a 3D printed hand. At the end of our second semester, we

expect to have a fully functioning robotic hand that will be tested on someone who has lost one

of their hands to regain simple capabilities such as picking up small objects.

## References

Advancer Technologies – Myoware Muscle Sensor

http://www.advancertechnologies.com/p/myoware.html

Backyard Brains – Signal Classification – Need an Extra Hand

https://backyardbrains.com/experiments/robothand

3D Print Design – Flexy-Hand 2

http://www.thingiverse.com/thing:380665

Intel Edison Kit for Arduino Hardware Guide

http://www.intel.com/content/dam/support/us/en/documents/edison/sb/edisonarduino_hg_331191007.pdf (http://www.intel.com/content/dam/support/us/en/documents/edison/sb/edisonarduino_hg_331191007.pdf)

Intel Edison MRAA Library

https://github.com/intel-iot-devkit/mraa

Intel Edison UPM Library

https://github.com/intel-iot-devkit/upm

JFreeChart Charting Library

http://www.jfree.org/jfreechart/

Plotly (Online Charting)

https://plot.ly/

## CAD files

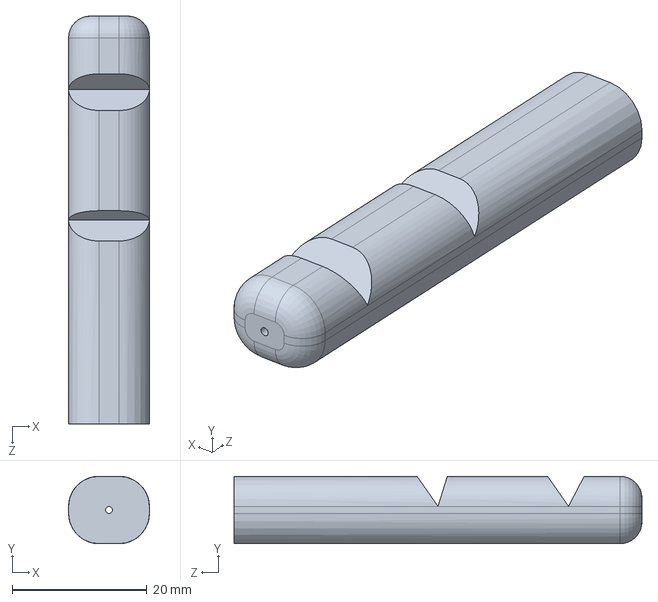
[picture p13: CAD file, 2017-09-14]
3D Hand Model/Finger Test/Finger 1.SLDPRT
12.0 x 10.0 x 60.5 mm

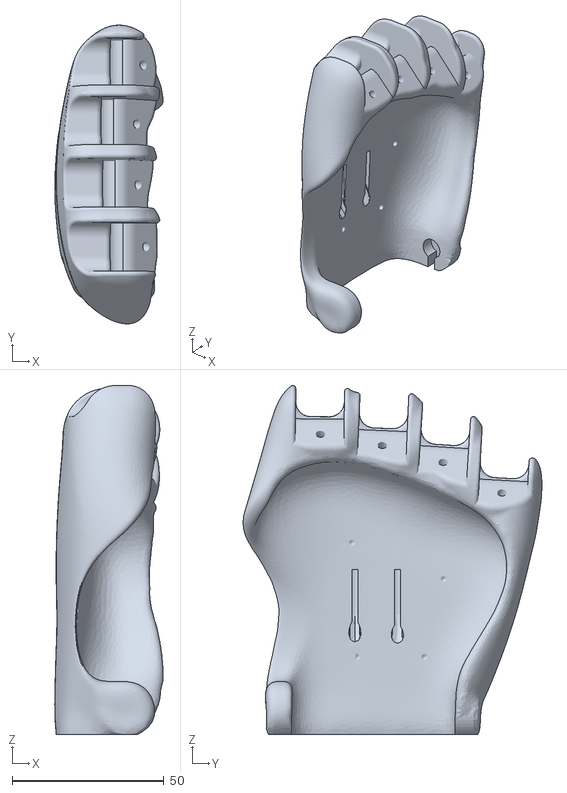
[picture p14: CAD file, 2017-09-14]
3D Hand Model/Flexy-Hand_2/LH_Hand_Body_-_No_Thumb.stl
35.7 x 98.3 x 114.9

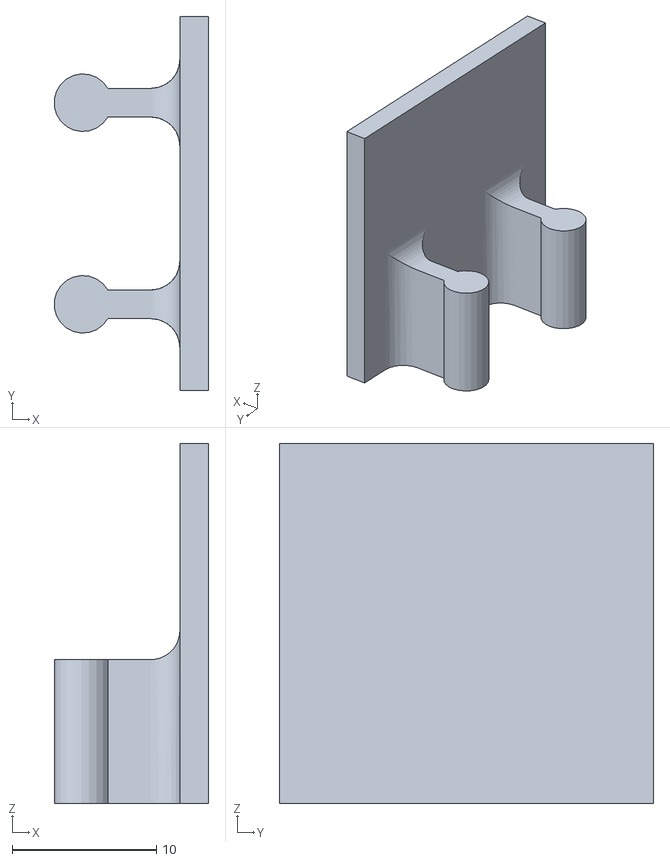
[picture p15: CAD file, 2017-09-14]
3D Hand Model/Flexy-Hand_2/FFX_-_Bat_Connection_-_Orientation_1.stl
10.7 x 26.0 x 25.0

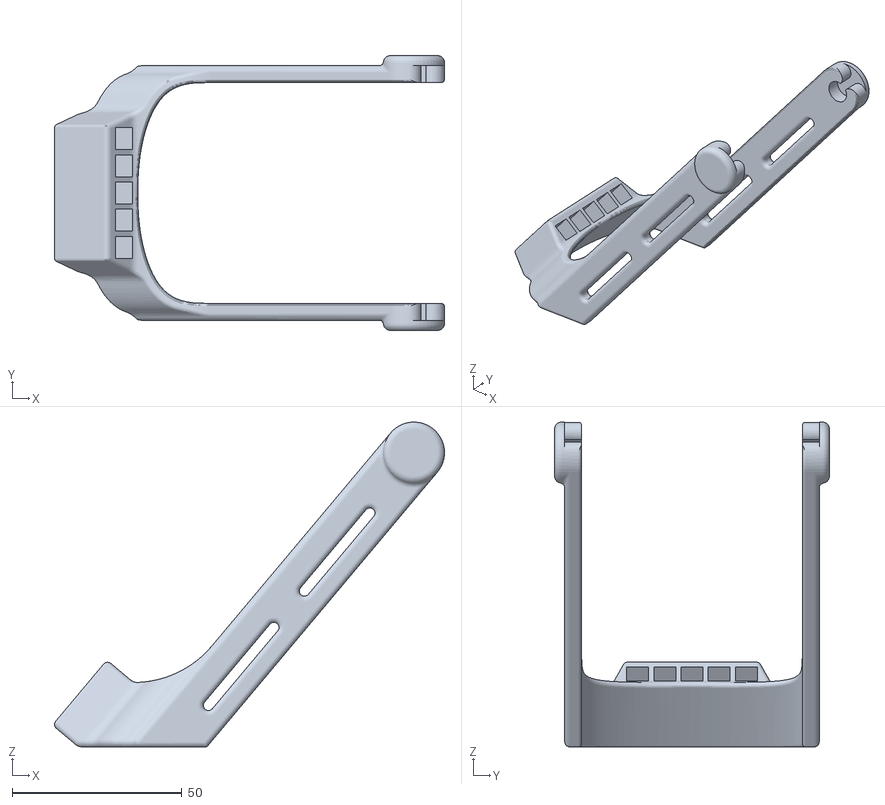
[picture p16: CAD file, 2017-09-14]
3D Hand Model/Flexy-Hand_2/Gauntlet_-_Long_Wider_Wrist.stl
114.9 x 81.0 x 95.7

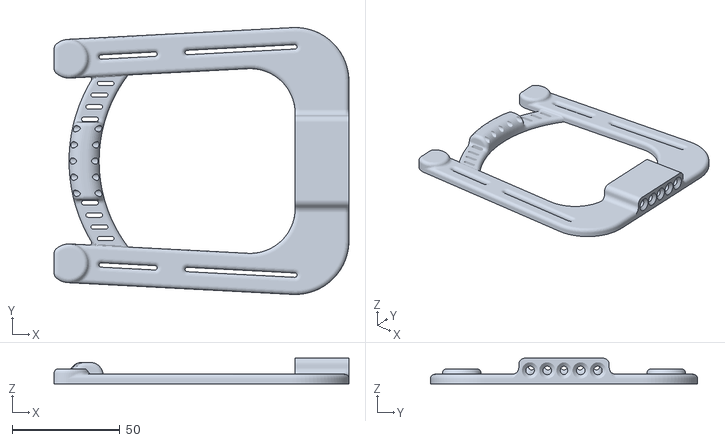
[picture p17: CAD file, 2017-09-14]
3D Hand Model/Flexy-Hand_2/Flexy-Hand_2_Gauntlet_-_Thermoform.stl
137.0 x 123.9 x 12.0

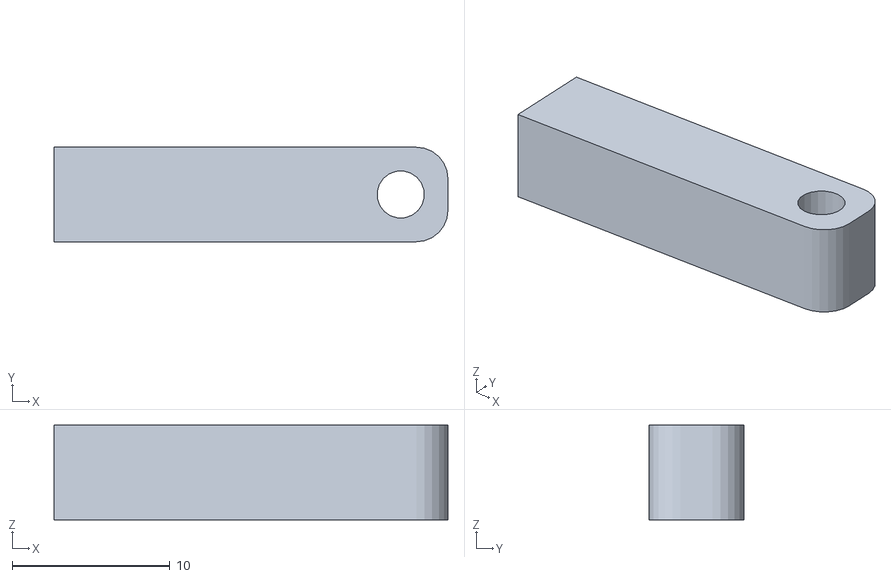
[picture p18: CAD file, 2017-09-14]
3D Hand Model/Flexy-Hand_2/Tensioner.stl
25.0 x 6.00 x 6.00

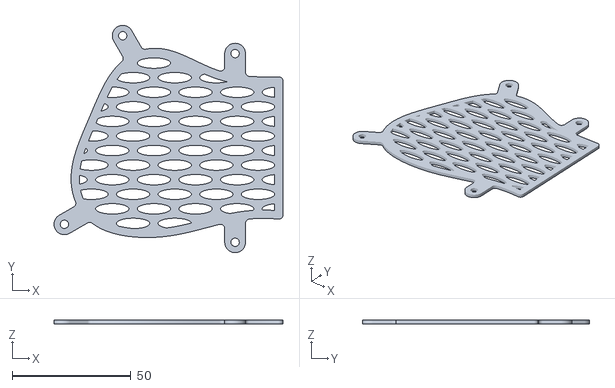
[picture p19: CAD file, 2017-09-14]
3D Hand Model/Flexy-Hand_2/ThermoForm_Palm_Mesh_Wide_Wrist.stl
96.2 x 95.5 x 1.53

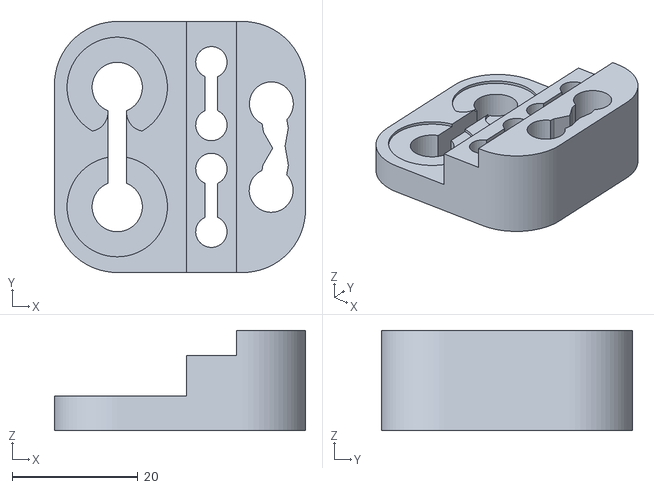
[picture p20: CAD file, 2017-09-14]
3D Hand Model/Flexy-Hand_2/Mould.stl
40.0 x 40.0 x 16.0

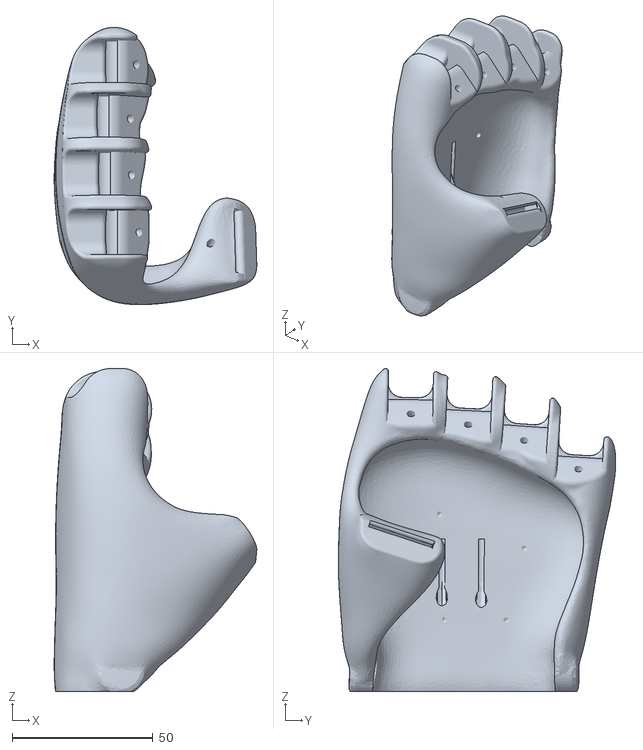
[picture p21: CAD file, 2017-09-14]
3D Hand Model/Flexy-Hand_2/LH_Hand_Body_-_Wider_Wrist_-_Opposable_Thumb.stl
72.1 x 98.6 x 114.9

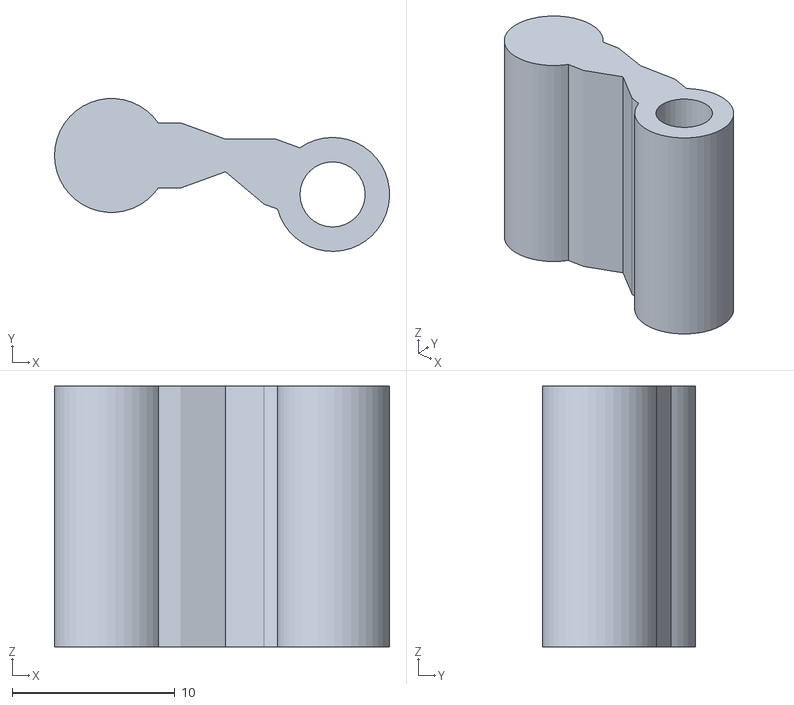
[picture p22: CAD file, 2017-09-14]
3D Hand Model/Flexy-Hand_2/7.stl
20.6 x 9.38 x 16.0

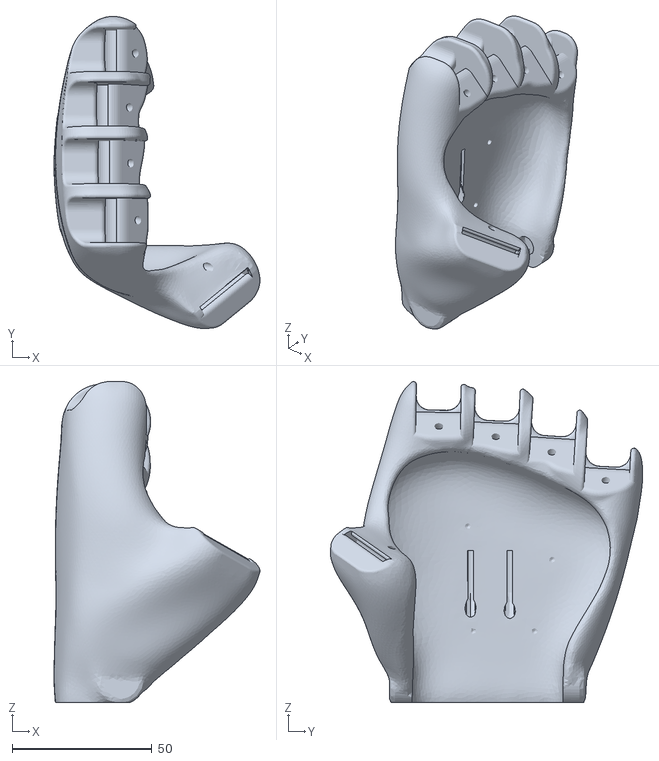
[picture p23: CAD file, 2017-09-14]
3D Hand Model/Flexy-Hand_2/LH_Hand_Body.stl
73.7 x 111.7 x 114.9

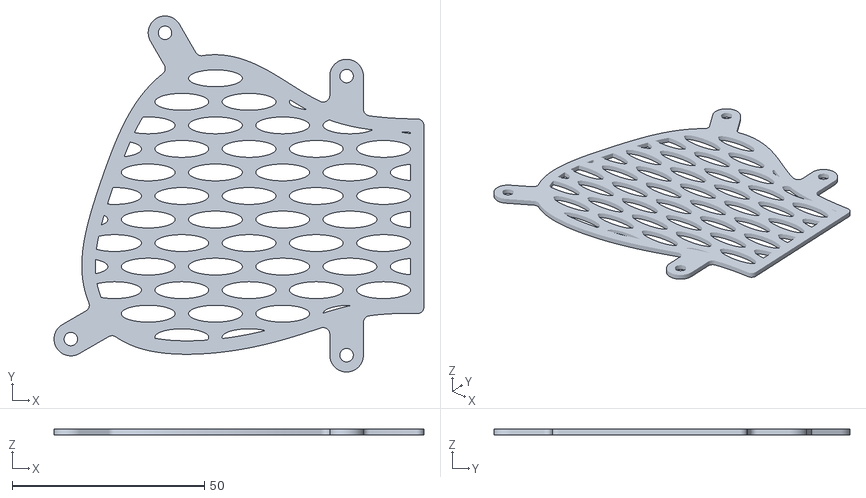
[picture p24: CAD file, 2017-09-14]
3D Hand Model/Flexy-Hand_2/ThermoForm_Palm_Mesh.stl
96.3 x 92.6 x 1.53

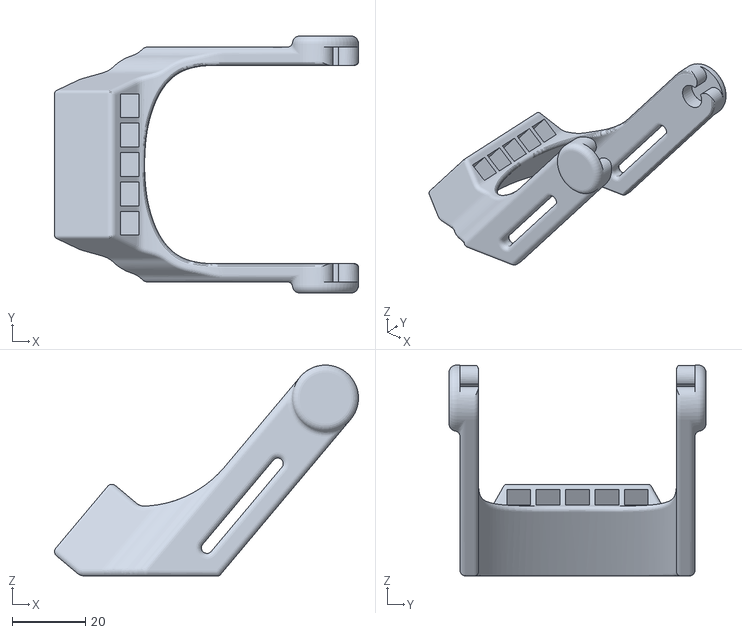
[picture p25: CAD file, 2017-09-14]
3D Hand Model/Flexy-Hand_2/Gauntlet_-_Short.stl
82.8 x 70.0 x 57.4

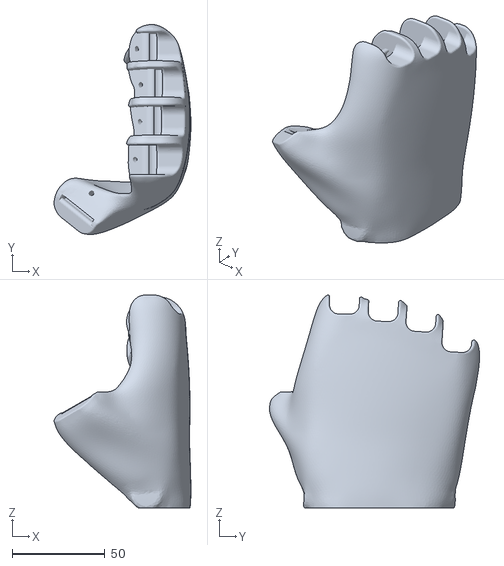
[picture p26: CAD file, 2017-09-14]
3D Hand Model/Flexy-Hand_2/RH_Hand_Body_-_Wider_Wrist.stl
73.8 x 113.3 x 114.9

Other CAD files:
3D Hand Model/Flexy-Hand_2/RH_Hand_Body.stl
3D Hand Model/Flexy-Hand_2/8.stl
3D Hand Model/Flexy-Hand_2/LH_Finger_Plate.stl
3D Hand Model/Flexy-Hand_2/Gauntlet_-_Long.stl
3D Hand Model/Finger Test/Finger 1.STL
3D Hand Model/Flexy-Hand_2/FFX_-_Finger_Hinge_Plate.stl
3D Hand Model/Flexy-Hand_2/FFX_-_Flexy-Hinge_Wrist.stl
3D Hand Model/Flexy-Hand_2/Gauntlet_-_Short_Wider_Wrist.stl
3D Hand Model/Flexy-Hand_2/LH_Hand_Body_-_Wider_Wrist.stl
3D Hand Model/Flexy-Hand_2/LH_Hand_Body_-_Wider_Wrist_-_No_Thumb.stl
3D Hand Model/Flexy-Hand_2/RH_Finger_Plate.stl
3D Hand Model/Flexy-Hand_2/RH_Hand_Body_-_No_Thumb.stl
3D Hand Model/Flexy-Hand_2/RH_Hand_Body_-_Wider_Wrist_-_No_Thumb.stl
3D Hand Model/Flexy-Hand_2/RH_Hand_Body_-_Wider_Wrist_-_Opposable_Thumb.stl

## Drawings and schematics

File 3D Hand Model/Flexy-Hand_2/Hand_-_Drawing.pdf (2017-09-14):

EXPLODED VIEW; PROXIMAL AND DISTAL INTERPHALANGEAL

BILL OF MATERIALS

ITEM NUMBER | DESCRIPTION | NUMBER OFF

1-1 | THUMB PROXIMAL PHALANX | 1
1-2 | THUMB DISTAL PHALANX | 1
2-1 | INDEX PROXIMAL PHALANX | 1
2-2 | INDEX MIDDLE PHALANX | 1
2-3 | INDEX DISTAL PHALANX | 1
3-1 | LONG PROXIMAL PHALANX | 1
3-2 | LONG MIDDLE PHALANX | 1
3-3 | LONG DISTAL PHALANX | 1
4-1 | RING PROXIMAL PHALANX | 1
4-2 | RING MIDDLE PHALANX | 1
4-3 | RING DISTAL PHALANX | 1
5-1 | SMALL PROXIMAL PHALANX | 1
5-2 | SMALL MIDDLE PHALANX | 1
5-3 | SMALL DISTAL PHALANX | 1
6 | HAND BODY | 1
7 | PALMAR DIGITAL | 4

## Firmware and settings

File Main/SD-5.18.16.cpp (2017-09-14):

#include "mraa.hpp"
#include "es08a.h"
#include <stdio.h>
#include <string.h>
#include <stdlib.h>
#include <unistd.h>
#include <sys/socket.h>
#include <netinet/in.h>
#include <netdb.h>
#include <sstream>
#include <string>
#include <fstream>
#include <iostream>

#include <ctime>

using namespace std;
#define SSTR( x ) static_cast< std::ostringstream & >( \
		( std::ostringstream() << std::dec << x ) ).str()

int mmap(int, int, int, int, int);
void my_socket(int, int, int, int, int);
void readCalibration();
void Calibration();

int s0 = socket(AF_INET, SOCK_STREAM, 0);
char const *peerHost = "127.0.0.1";
short peerPort = 8589;
struct sockaddr_in peeraddr;

int pinky_val, ring_val, middle_val, index_val;
uint16_t pinky_servo, ring_servo, middle_servo, index_servo, thumb_servo;
int cali_val[10];
int pinky_low, pinky_high, ring_low, ring_high, middle_low, middle_high,
	index_low, index_high;

mraa::Aio* a0 = new mraa::Aio(0);
mraa::Aio* a1 = new mraa::Aio(1);
mraa::Aio* a2 = new mraa::Aio(2);
mraa::Aio* a3 = new mraa::Aio(3);

long systime = 0, systime2 = 0, tsystime = 0;
int main(){
	upm::ES08A *servo0 = new upm::ES08A(3);
	upm::ES08A *servo1 = new upm::ES08A(5);
	upm::ES08A *servo2 = new upm::ES08A(6);
	upm::ES08A *servo3 = new upm::ES08A(9);
	servo0->setAngle (180);
	servo1->setAngle (180);
	servo2->setAngle (180);
	servo3->setAngle (180);
    Calibration();
    readCalibration();

	int pinky_low = cali_val[0],   pinky_high = cali_val[1],
		ring_low = cali_val[2],    ring_high = cali_val[3],
		middle_low = cali_val[4],  middle_high = cali_val[5],
		index_low = cali_val[6],   index_high = cali_val[7],
		thumb_low = cali_val[8],   thumb_high = cali_val[9];
	memset(&peeraddr, 0, sizeof(peeraddr));
	struct hostent *host = gethostbyname(peerHost);
	peeraddr.sin_family = AF_INET;
	peeraddr.sin_port = htons(peerPort);
	memmove(&(peeraddr.sin_addr.s_addr), host->h_addr_list[0], 4);
	//connect(s0, (struct sockaddr*) &peeraddr, sizeof(peeraddr));
	int count = 0;
	int samples = 30;
    for (;;) {
    	//systime = time(0);

    	usleep(3000);
        pinky_val += a0->read();
        ring_val += a1->read();
        middle_val += a2->read();
        index_val += a3->read();

        //my_socket(pinky_val,ring_val,middle_val,index_val,0);
        //printf("This is the min: %d, max: %d, value: %d\n", ring_low, ring_high, ring_val);
		if(count == samples){
			pinky_val = (((pinky_val+5)/10) * 10)/samples;
			ring_val = (((ring_val+5)/10) * 10)/samples;
			middle_val = (((middle_val+5)/10) * 10)/samples;
			index_val = (((index_val+5)/10) * 10)/samples;
			if((pinky_low) < pinky_val && pinky_val < (pinky_high + 1)){
				pinky_servo = mmap(pinky_val, pinky_low, pinky_high, 180, 0);
				servo0->setAngle (pinky_servo);
			}
			if((ring_low) < ring_val && ring_val < (ring_high + 1)){
				ring_servo = mmap(ring_val, ring_low, ring_high, 180, 0);
				//printf("Ring Servo: %d\n",ring_servo);
				servo1->setAngle (ring_servo);
			}

			if((middle_low) < middle_val && middle_val < (middle_high + 1)){
				middle_servo = mmap(middle_val, middle_low, middle_high, 180, 0);
				servo2->setAngle (middle_servo);
			}
			if((index_low) < index_val && index_val < (index_high + 1)){
				index_servo = mmap(index_val, index_low, index_high, 180, 0);
				servo3->setAngle (index_servo);
			}
			//systime2 = time(0);
			//tsystime = systime2 - systime;
			//printf("Looptime in us: %L\n", systime);
			count = 0;
		}
		count++;
    }
    close(s0);
    return MRAA_SUCCESS;
}

int mmap(int x, int in_min, int in_max, int out_min, int out_max){
	return (x - in_min) * (out_max - out_min) / (in_max - in_min) + out_min;
}

void readCalibration(){
	ifstream file("/home/root/calibration.txt");
	if(file.is_open()){
		for(int i = 0; i < 10; i++){
			file >> cali_val[i];
		}
	}
	file.close();
}
void Calibration(){
	int tmparray[10] = {0,0,0,0,0,0,0,0,0,0};
	int count;
	int tmpvar = 0;
	int samples = 1500;
	//calibration process
	printf("Order of calibration: Pinky, Ring, Middle, Index, Thumb\n");
	printf("Calibrate each finger twice: Baseline, then Max\n");
	printf("Calibration process will start in 3 seconds\n");
	printf("\n");
	sleep(3);

	printf("Calibrating Baseline for Pinky\n");
	for(count = 0; count < samples; count++){
		tmpvar += a0->read();
		usleep(5000);
	}
	tmparray[0] = tmpvar/samples;
	tmpvar = 0;
	printf("Calibrating Max for Pinky\n");
	for(count = 0; count < samples; count++){
		tmpvar += a0->read();
		usleep(5000);
	}

	tmparray[1] = tmpvar/samples;
	tmpvar = 0;

	printf("Calibrating Baseline for Ring\n");
	for(count = 0; count < samples; count++){
		tmpvar += a1->read();
		usleep(5000);
	}
	tmparray[2] = tmpvar/samples;
	tmpvar = 0;
	printf("Calibrating Max for Ring\n");
	for(count = 0; count < samples; count++){
		tmpvar += a1->read();
		usleep(5000);
	}
	tmparray[3] = tmpvar/samples;
	tmpvar = 0;

	printf("Calibrating Baseline for Middle/Index\n");
	for(count = 0; count < samples; count++){
		tmpvar += a2->read();
		usleep(5000);
	}
	tmparray[4] = tmpvar/samples;
	tmpvar = 0;
	printf("Calibrating Max for Middle/Index\n");
	for(count = 0; count < samples; count++){
		tmpvar += a2->read();
		usleep(5000);
	}
	tmparray[5] = tmpvar/samples;
	tmpvar = 0;

	printf("Calibrating Baseline for Thumb\n");
	for(count = 0; count < samples; count++){
		tmpvar += a3->read();
		usleep(5000);
	}
	tmparray[6] = tmpvar/samples;
	tmpvar = 0;
	printf("Calibrating Max for Thumb\n");
	for(count = 0; count < samples; count++){
		tmpvar += a3->read();
		usleep(5000);
	}
	tmparray[7] = tmpvar/samples;
	tmpvar = 0;

	//end of calibration process
	ofstream file("/home/root/calibration.txt");
	if(file.is_open()){
		for(int i = 0; i < 10; i++){
			file << tmparray[i];
			file << " ";
		}
	}
	file.close();
	printf("Calibration Finished...\n");
}

void my_socket(int sval1, int sval2, int sval3, int sval4, int sval5){
	const void *data;
	std::string sensor1 = SSTR( sval1 );
	std::string sensor2 = SSTR( sval2 );
	std::string sensor3 = SSTR( sval3 );
	std::string sensor4 = SSTR( sval4 );
	std::string sensor5 = SSTR( sval5 );
	std::string my_string = sensor1 + "," + sensor2 + "," + sensor3 + "," + sensor4 + "," + sensor5;
	data = my_string.c_str();
	write(s0, data, 20);
}

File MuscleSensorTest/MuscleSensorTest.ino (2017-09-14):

int led = 3;
int muscleValue = 0;
int ledValue = 0;

void setup() {
  // put your setup code here, to run once:
  pinMode(led, OUTPUT);
  Serial.begin(9600);
  Serial.println("Muscle Sensor Test");
}

void loop() {
  muscleValue = analogRead(A0);
  Serial.print("Muscle Value: ");
  Serial.println(muscleValue);
  analogWrite(led, muscleValue);
}
